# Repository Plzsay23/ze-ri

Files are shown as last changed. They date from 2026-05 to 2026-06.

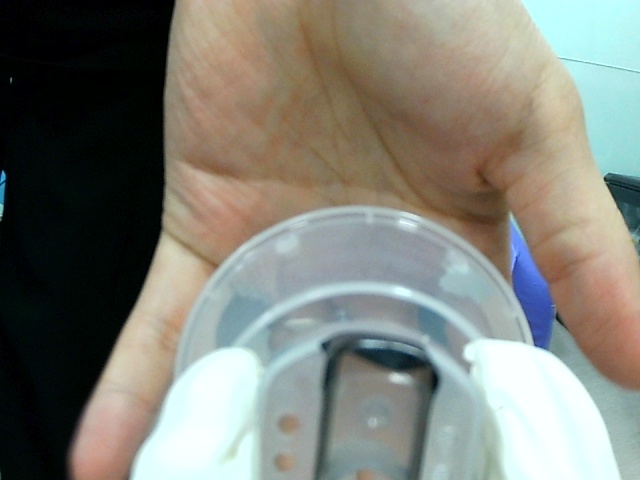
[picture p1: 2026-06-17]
debug/yolo_handoff/20260604_195928_raw.jpg

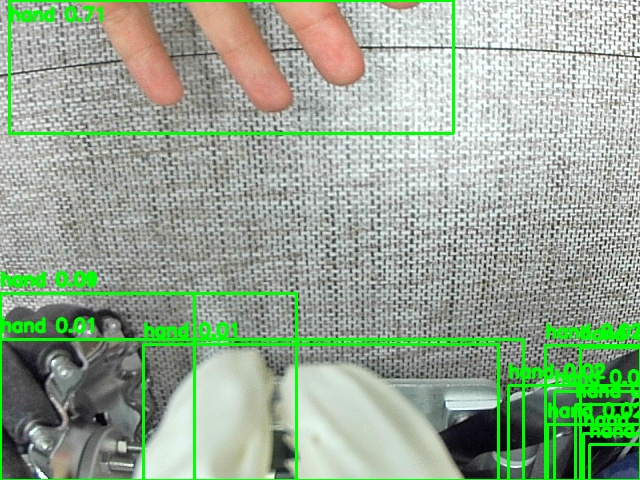
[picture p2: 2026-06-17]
debug/yolo_handoff/20260604_193629_yolo.jpg

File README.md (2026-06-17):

# Zero-Risk

Zero-Risk는 재난 상황 초동 조치를 위한 VLM 기반 지능형 모바일 매니퓰레이터입니다. RGB-D 카메라, 2D LiDAR, ReSpeaker Mic Array, SenseVoice STT, Edge-TTS, Qwen3-VL, SO-101 양팔 로봇팔, 4륜 메카넘 베이스를 ROS2 Jazzy 토픽으로 연결합니다.

## 주요 기능

- RGB-D 카메라와 LiDAR 기반 사람 접근 및 안전 정지
- ReSpeaker VAD/DOA와 SenseVoice 기반 음성 입력
- Edge-TTS 기반 구조 안내 발화
- Qwen3-VL 기반 구조 대상자 요청 판단
- 물, 산소마스크, 무전기 전달 VLA task routing
- SO-101 양팔 로봇팔 기반 물품 집기와 전달
- RGB, Depth, PointCloud, STT, TTS, VLM, VLA, 자율주행 상태 대시보드

## 환경

- Ubuntu 24.04
- ROS2 Jazzy
- Python 3.12
- NVIDIA Jetson Thor
- Intel RealSense D435i/D435if
- EAI X2 2D LiDAR
- ReSpeaker USB Mic Array v3.0
- SO-101 robot arm 2대

## 빌드

```bash
cd ~/ze-ri
source /opt/ros/jazzy/setup.bash
colcon build --base-paths ros2_ws/src --symlink-install
source ~/ze-ri/source_zeri.sh
```

## 수동 실행

각 명령은 별도 터미널에서 실행합니다.

```bash
cd ~/ze-ri
source ~/ze-ri/source_zeri.sh
```

카메라:

```bash
bash ~/ze-ri/scripts/camera_rgbd.sh
```

SLAM, LiDAR safety, base odometry:

```bash
bash ~/ze-ri/scripts/slam_depth_drive.sh
```

음성 방향 주행은 SLAM/base stack을 먼저 켠 뒤 실행합니다:

```bash
bash ~/ze-ri/scripts/voice_direction_drive.sh
```

STT, TTS, VLM:

```bash
bash ~/ze-ri/scripts/start_hri.sh
```

양팔 VLA:

```bash
bash ~/ze-ri/scripts/start_vla.sh
```

대시보드:

```bash
python3 ~/ze-ri/dashboard/dashboard_server.py
```

## 주요 토픽

- `/zeri/vlm/input_rgb`
- `/zeri/vlm/input_depth`
- `/stt/text`
- `/zeri/vlm/robot_speech`
- `/zeri/vlm/decision`
- `/zeri/vla/task_request`
- `/zeri/vla/status`
- `/cmd_vel_raw`
- `/cmd_vel`
- `/odom`
- `/scan_front`
- `/map`

## 스모크 테스트

```bash
python3 -m py_compile \
  ros2_ws/src/nb_voice_stt/nb_voice_stt/*.py \
  ros2_ws/src/zeri_base/zeri_base/*.py \
  ros2_ws/src/zeri_bringup/zeri_bringup/*.py \
  ros2_ws/src/zeri_camera/zeri_camera/*.py \
  ros2_ws/src/zeri_lidar/zeri_lidar/*.py \
  ros2_ws/src/zeri_voice/zeri_voice/*.py \
  src/lerobot/vlm_agent/*.py

python3 - <<'PY'
from pathlib import Path
import xml.etree.ElementTree as ET
for path in Path("ros2_ws/src").glob("*/package.xml"):
    ET.parse(path)
print("package.xml ok")
PY

bash -n source_zeri.sh source_zeri_vlm.sh scripts/*.sh
```

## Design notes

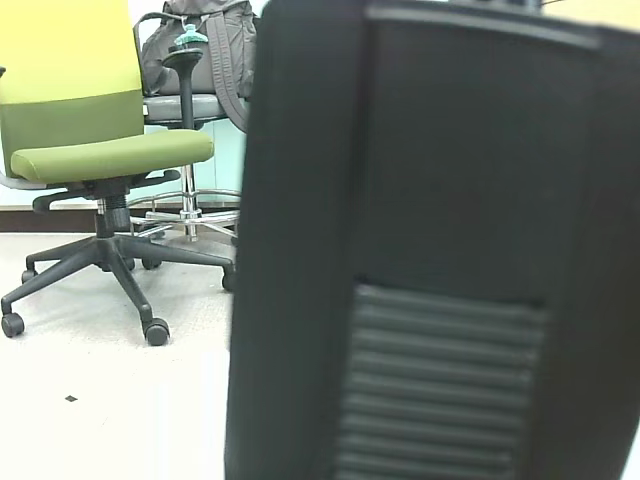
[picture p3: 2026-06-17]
config/vla/references/pick_wt/final_ep_0008.png

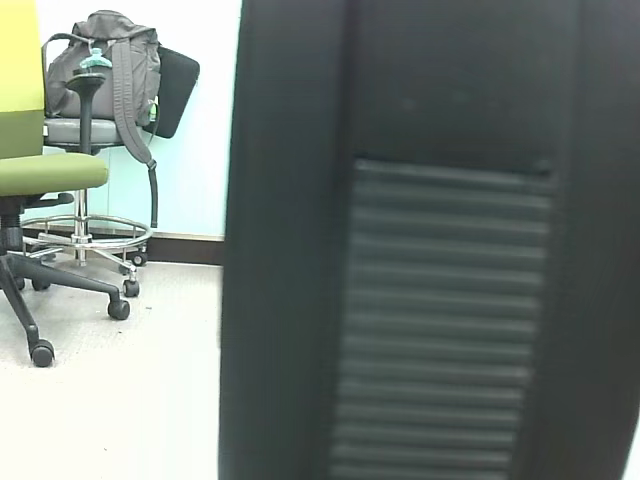
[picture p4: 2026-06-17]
config/vla/references/pick_wt/final_ep_0003.png

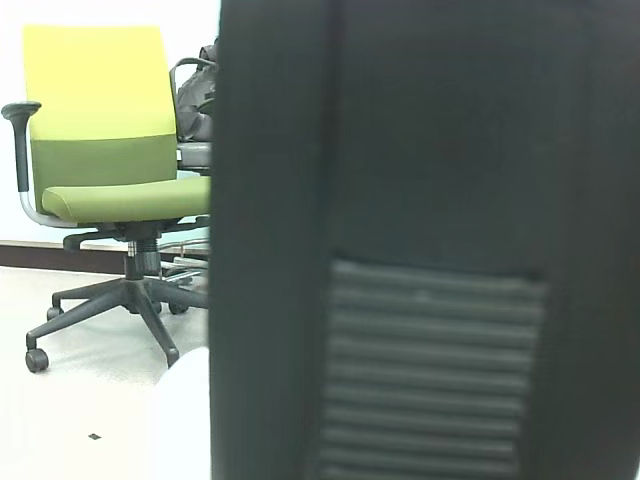
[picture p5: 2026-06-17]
config/vla/references/pick_wt/final_ep_0020.png

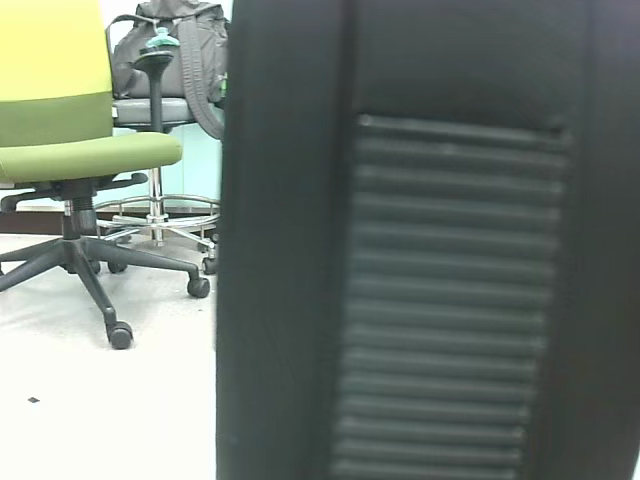
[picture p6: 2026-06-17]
config/vla/references/pick_wt/final_ep_0023.png

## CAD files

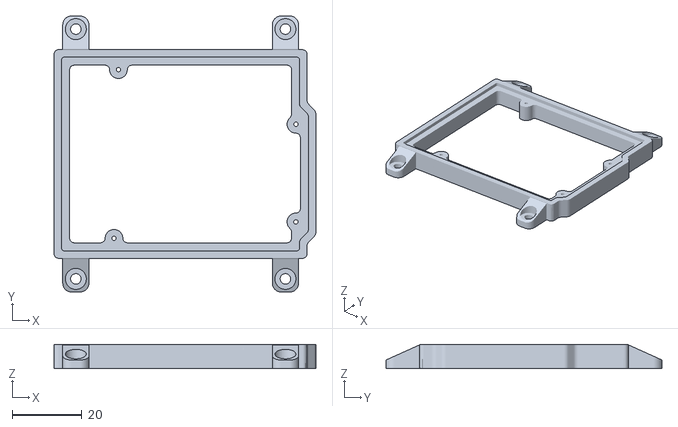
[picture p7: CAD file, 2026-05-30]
stl/mount/Mount_arduino.stl
74.9 x 79.0 x 7.00

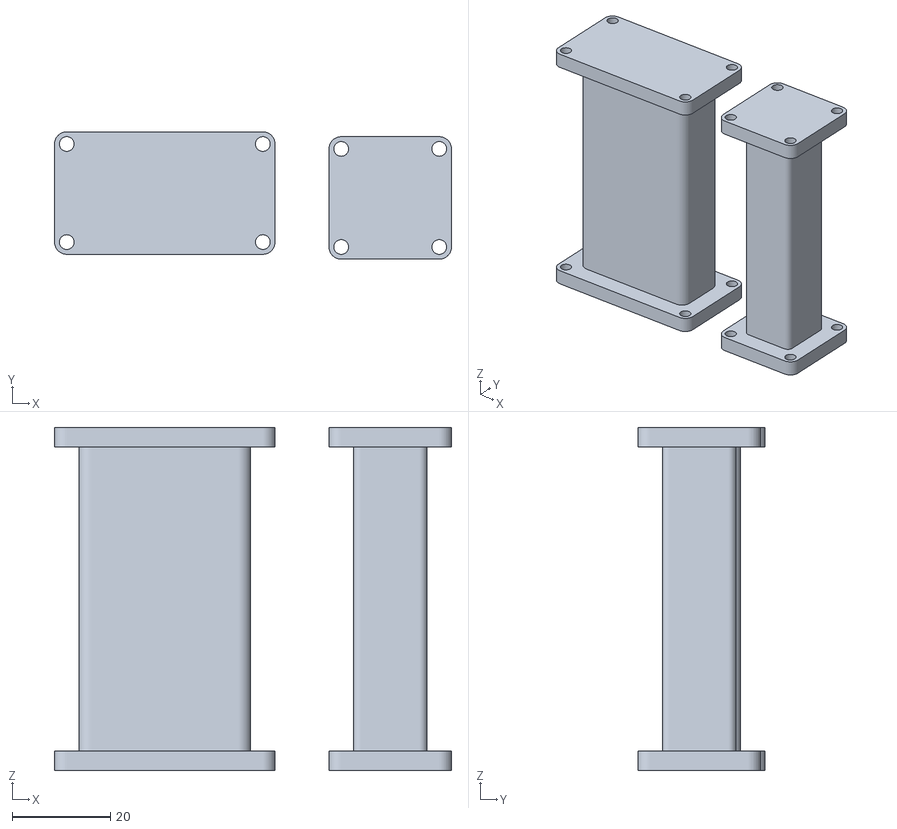
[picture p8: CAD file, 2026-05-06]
stl/others/Pillar.stl
81.0 x 26.0 x 70.0

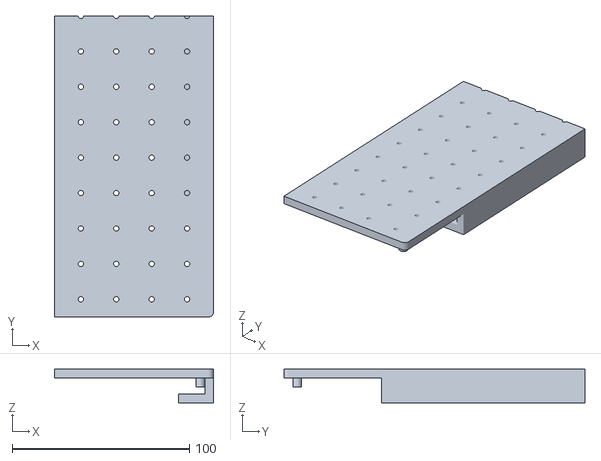
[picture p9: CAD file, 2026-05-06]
stl/plate/Plate_base_back_right.stl
90.0 x 170.0 x 19.0

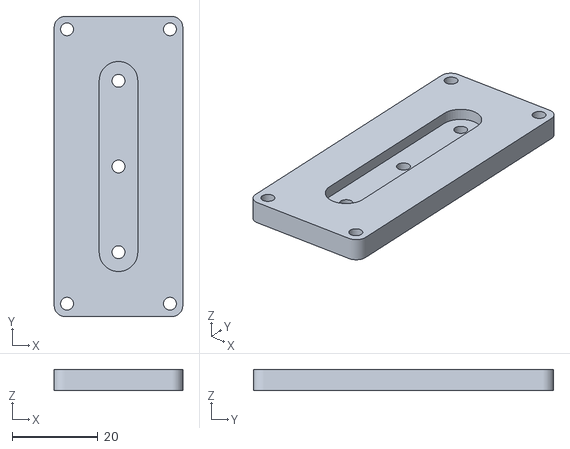
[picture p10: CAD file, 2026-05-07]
stl/mount/Mount_speaker.stl
30.0 x 70.0 x 5.00

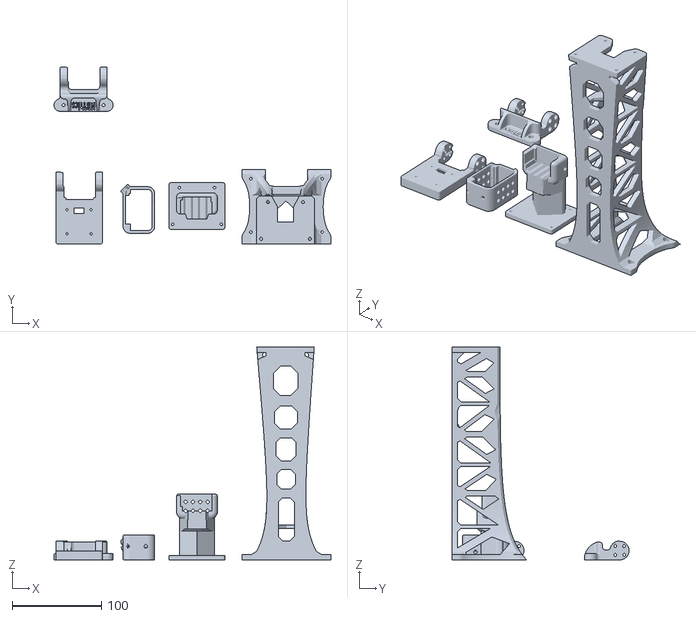
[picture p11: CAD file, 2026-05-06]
stl/others/Tower_camera.stl
311.0 x 198.9 x 239.0

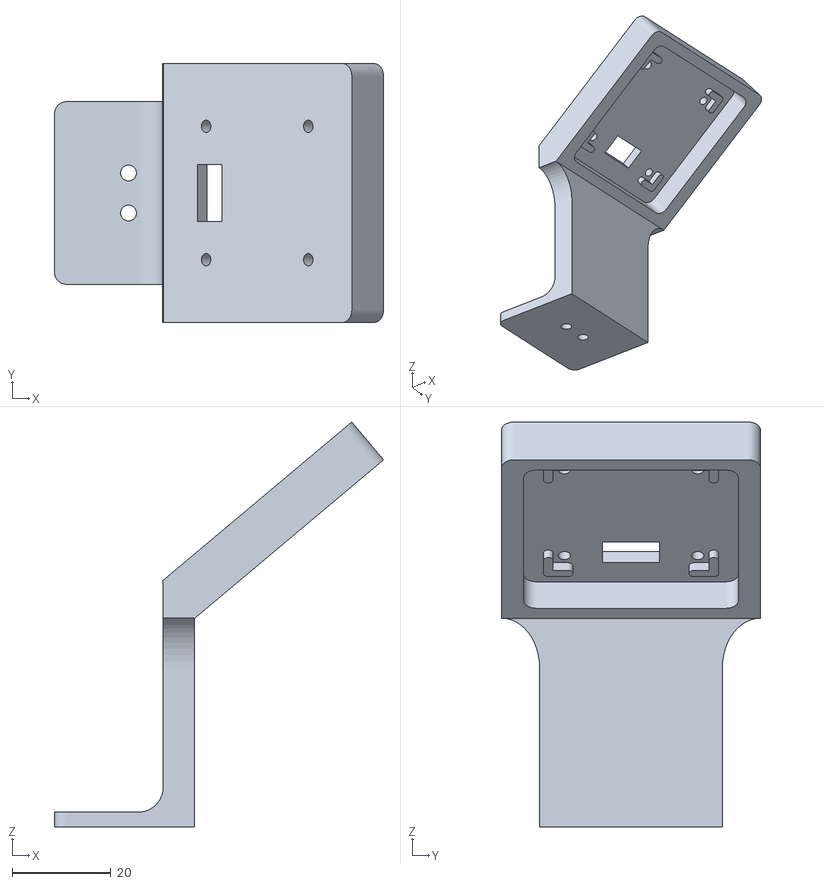
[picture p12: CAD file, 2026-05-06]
stl/mount/Mount_wrist_camera.stl
66.6 x 52.4 x 82.0

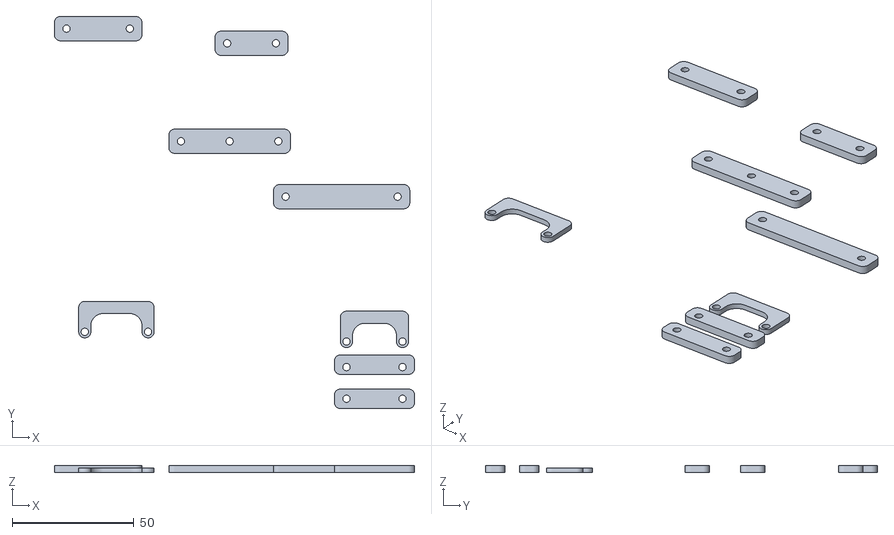
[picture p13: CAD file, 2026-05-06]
stl/others/Connectors.stl
148.0 x 161.0 x 3.00

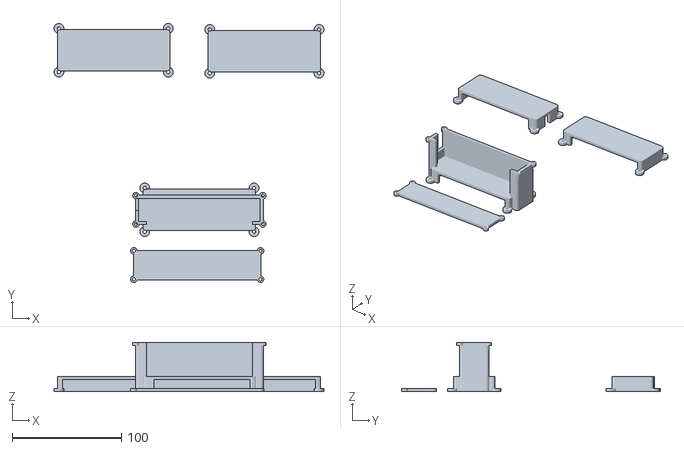
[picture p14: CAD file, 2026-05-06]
stl/mount/Mount_USB_hub.stl
247.0 x 237.0 x 45.0

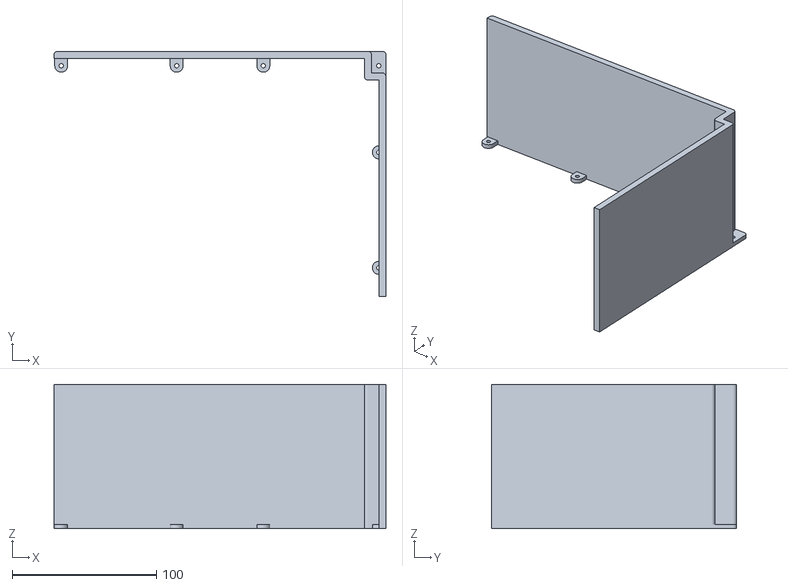
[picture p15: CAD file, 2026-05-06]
stl/others/Fence_left.stl
230.0 x 170.0 x 100.0

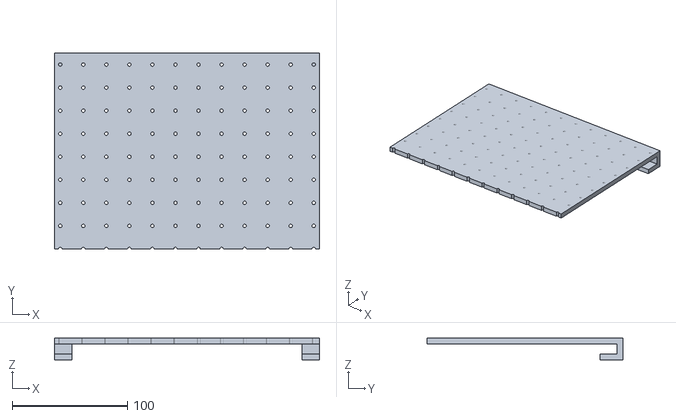
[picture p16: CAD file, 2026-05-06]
stl/plate/Plate_base_middle.stl
230.0 x 170.0 x 19.0

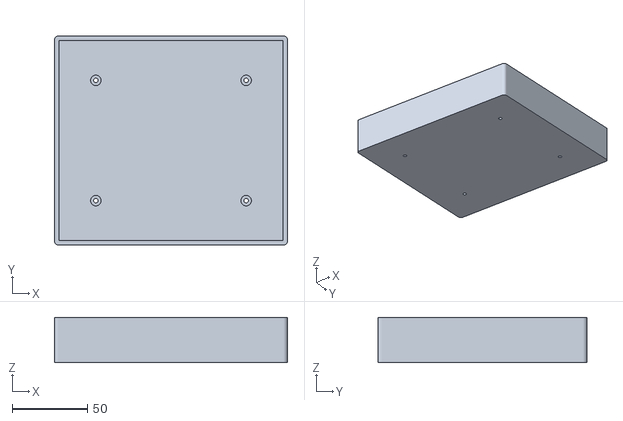
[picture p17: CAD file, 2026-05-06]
stl/mount/Mount_battery_16v.stl
155.0 x 139.0 x 30.0

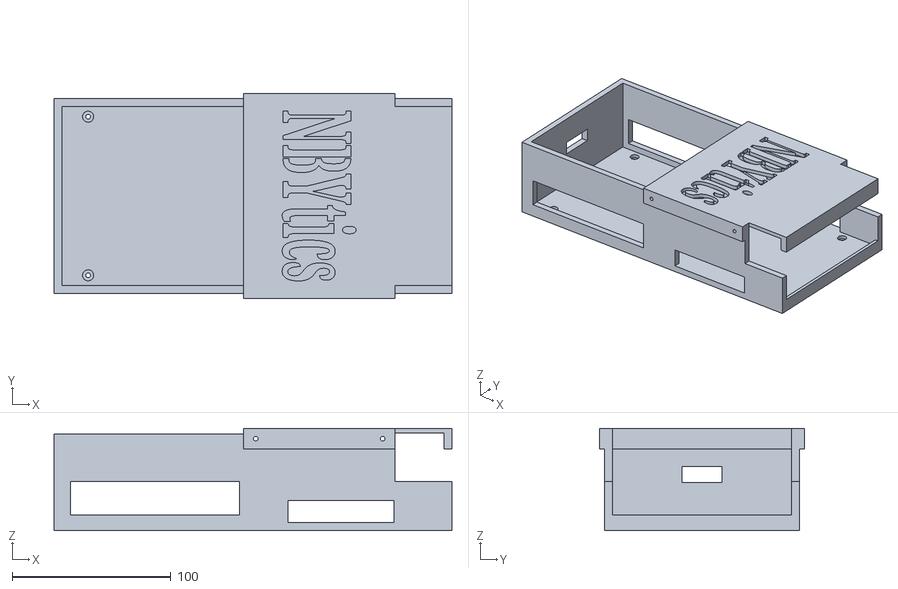
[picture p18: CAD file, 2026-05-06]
stl/mount/Mount_jetson_thor.stl
251.0 x 129.0 x 64.5

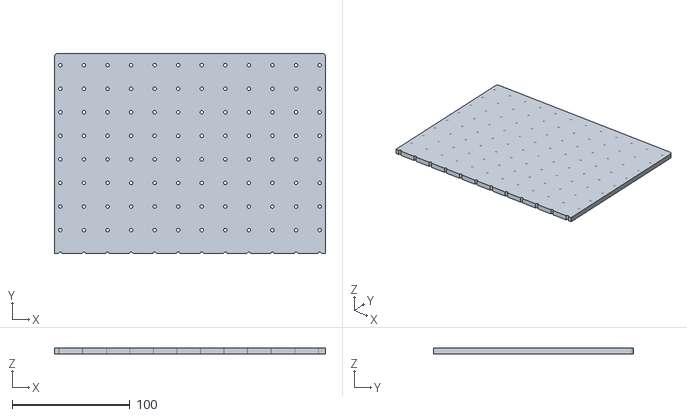
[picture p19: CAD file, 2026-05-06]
stl/plate/Plate_top.stl
230.0 x 170.0 x 5.00

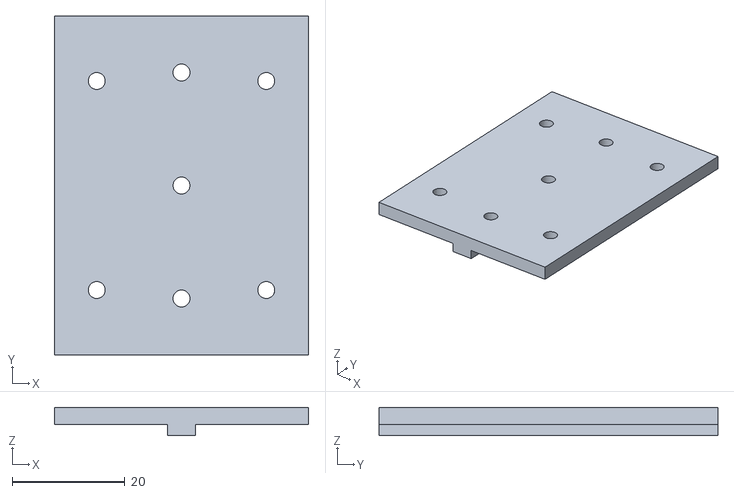
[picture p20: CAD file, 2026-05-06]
stl/mount/Mount_driver.stl
45.0 x 60.0 x 5.00

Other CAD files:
stl/plate/Plate_base_front_right.stl
stl/plate/Plate_base_back_left.stl
stl/others/Fence_right.stl
stl/plate/Plate_base_front_left.stl
stl/mount/Mount_battery_12v.stl
stl/mount/Mount_microphone.stl

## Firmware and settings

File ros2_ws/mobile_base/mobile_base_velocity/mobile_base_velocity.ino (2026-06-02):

#include <Encoder.h>
#include <math.h>
#include <string.h>

// ============================================================
// Ze-Ri Mobile Base Arduino Firmware
//
// Protocol:
//   V vx vy wz\n     vx, vy, wz in [-1.0, 1.0]
//   P pwm\n          set max PWM
//   X\n              smooth stop
//   Z\n              immediate stop
//
// IMPORTANT:
//   Acceleration command is NOT accepted.
//   There is NO "A accel decel" serial command.
//   Ramp values are fixed inside this firmware.
//
// Legacy lowercase keys for manual test:
//   w/s : forward/backward
//   a/d : turn left/right
//   q/e : strafe left/right
//   r/t/f/g : diagonal
//   x : smooth stop
//   z : immediate stop
//   l/m : PWM +10 / -10
//
// Encoder output:
//   ENC LF RF LR RR
// ============================================================


// ============================================================
// Motor pins
// ============================================================

#define PWMA 4
#define DIRA1 A5
#define DIRA2 A4

#define PWMB 6
#define DIRB1 43
#define DIRB2 42

#define PWMC 11
#define DIRC1 35
#define DIRC2 34

#define PWMD 7
#define DIRD1 37
#define DIRD2 36


// ============================================================
// Encoder pins
//
// Actual motor mapping:
//   A = RF
//   B = LF, inverted
//   C = RR
//   D = LR, inverted
// ============================================================

Encoder encA(18, 31);   // RF
Encoder encB(19, 38);   // LF, inverted
Encoder encC(3, 49);    // RR
Encoder encD(2, A1);    // LR, inverted


// ============================================================
// Speed / timing
// ============================================================

int Motor_PWM = 60;

const int MIN_MOTION_PWM = 18;

const unsigned long ENC_PERIOD_MS = 100;
const unsigned long CMD_TIMEOUT_MS = 800;
const unsigned long RAMP_PERIOD_MS = 20;

unsigned long lastEncMs = 0;
unsigned long lastCmdMs = 0;
unsigned long lastRampMs = 0;


// ============================================================
// Fixed internal ramp
//
// These values are NOT configurable through serial.
// Arduino must NOT receive acceleration/deceleration values.
// ============================================================

const float RAMP_UP_STEP = 0.025f;
const float RAMP_DOWN_STEP = 0.040f;


// ============================================================
// Wheel command state
//
// Wheel order:
//   LF RF LR RR
// ============================================================

float targetLF = 0.0f;
float targetRF = 0.0f;
float targetLR = 0.0f;
float targetRR = 0.0f;

float currentLF = 0.0f;
float currentRF = 0.0f;
float currentLR = 0.0f;
float currentRR = 0.0f;


// ============================================================
// Serial line buffer
// ============================================================

char lineBuf[96];
uint8_t lineLen = 0;
bool lineMode = false;


// ============================================================
// Motor low-level macros
// ============================================================

#define MOTORA_FORWARD(pwm)    do { digitalWrite(DIRA1, HIGH); digitalWrite(DIRA2, LOW);  analogWrite(PWMA, pwm); } while (0)
#define MOTORA_BACKOFF(pwm)    do { digitalWrite(DIRA1, LOW);  digitalWrite(DIRA2, HIGH); analogWrite(PWMA, pwm); } while (0)
#define MOTORA_STOP()          do { digitalWrite(DIRA1, LOW);  digitalWrite(DIRA2, LOW);  analogWrite(PWMA, 0);   } while (0)

#define MOTORB_FORWARD(pwm)    do { digitalWrite(DIRB1, LOW);  digitalWrite(DIRB2, HIGH); analogWrite(PWMB, pwm); } while (0)
#define MOTORB_BACKOFF(pwm)    do { digitalWrite(DIRB1, HIGH); digitalWrite(DIRB2, LOW);  analogWrite(PWMB, pwm); } while (0)
#define MOTORB_STOP()          do { digitalWrite(DIRB1, LOW);  digitalWrite(DIRB2, LOW);  analogWrite(PWMB, 0);   } while (0)

#define MOTORC_FORWARD(pwm)    do { digitalWrite(DIRC1, HIGH); digitalWrite(DIRC2, LOW);  analogWrite(PWMC, pwm); } while (0)
#define MOTORC_BACKOFF(pwm)    do { digitalWrite(DIRC1, LOW);  digitalWrite(DIRC2, HIGH); analogWrite(PWMC, pwm); } while (0)
#define MOTORC_STOP()          do { digitalWrite(DIRC1, LOW);  digitalWrite(DIRC2, LOW);  analogWrite(PWMC, 0);   } while (0)

#define MOTORD_FORWARD(pwm)    do { digitalWrite(DIRD1, LOW);  digitalWrite(DIRD2, HIGH); analogWrite(PWMD, pwm); } while (0)
#define MOTORD_BACKOFF(pwm)    do { digitalWrite(DIRD1, HIGH); digitalWrite(DIRD2, LOW);  analogWrite(PWMD, pwm); } while (0)
#define MOTORD_STOP()          do { digitalWrite(DIRD1, LOW);  digitalWrite(DIRD2, LOW);  analogWrite(PWMD, 0);   } while (0)


// ============================================================
// Utility
// ============================================================

float clampf(float x, float lo, float hi) {
  if (x < lo) return lo;
  if (x > hi) return hi;
  return x;
}

bool oppositeSign(float a, float b, float eps) {
  return fabs(a) > eps && fabs(b) > eps && (a * b) < 0.0f;
}

int scaledPwm(float v) {
  float a = fabs(v);

  if (a < 0.001f) {
    return 0;
  }

  int pwm = (int)(a * Motor_PWM + 0.5f);

  if (pwm > 0 && pwm < MIN_MOTION_PWM) {
    pwm = MIN_MOTION_PWM;
  }

  if (pwm > 255) {
    pwm = 255;
  }

  return pwm;
}


// ============================================================
// Motor signed output
// ============================================================

void motorA_signed(float v) {
  int pwm = scaledPwm(v);

  if (pwm == 0) {
    MOTORA_STOP();
  } else if (v > 0.0f) {
    MOTORA_FORWARD(pwm);
  } else {
    MOTORA_BACKOFF(pwm);
  }
}

void motorB_signed(float v) {
  int pwm = scaledPwm(v);

  if (pwm == 0) {
    MOTORB_STOP();
  } else if (v > 0.0f) {
    MOTORB_FORWARD(pwm);
  } else {
    MOTORB_BACKOFF(pwm);
  }
}

void motorC_signed(float v) {
  int pwm = scaledPwm(v);

  if (pwm == 0) {
    MOTORC_STOP();
  } else if (v > 0.0f) {
    MOTORC_FORWARD(pwm);
  } else {
    MOTORC_BACKOFF(pwm);
  }
}

void motorD_signed(float v) {
  int pwm = scaledPwm(v);

  if (pwm == 0) {
    MOTORD_STOP();
  } else if (v > 0.0f) {
    MOTORD_FORWARD(pwm);
  } else {
    MOTORD_BACKOFF(pwm);
  }
}


// ============================================================
// Wheel ramp
// ============================================================

float slewWheel(float current, float target) {
  target = clampf(target, -1.0f, 1.0f);

  // Avoid direct reverse. Pass through zero first.
  if (oppositeSign(current, target, 0.02f)) {
    target = 0.0f;
  }

  float diff = target - current;

  if (fabs(diff) < 0.0005f) {
    return target;
  }

  float step;

  if (fabs(target) < fabs(current)) {
    step = RAMP_DOWN_STEP;
  } else {
    step = RAMP_UP_STEP;
  }

  if (fabs(diff) <= step) {
    return target;
  }

  if (diff > 0.0f) {
    return current + step;
  }

  return current - step;
}

void setWheelTargets(float lf, float rf, float lr, float rr) {
  targetLF = clampf(lf, -1.0f, 1.0f);
  targetRF = clampf(rf, -1.0f, 1.0f);
  targetLR = clampf(lr, -1.0f, 1.0f);
  targetRR = clampf(rr, -1.0f, 1.0f);
}

void applyCurrentWheels() {
  // Actual motor mapping:
  //   A = RF
  //   B = LF
  //   C = RR
  //   D = LR
  motorB_signed(currentLF);
  motorA_signed(currentRF);
  motorD_signed(currentLR);
  motorC_signed(currentRR);
}

void updateMotorRamp() {
  unsigned long now = millis();

  if (now - lastRampMs < RAMP_PERIOD_MS) {
    return;
  }

  lastRampMs = now;

  currentLF = slewWheel(currentLF, targetLF);
  currentRF = slewWheel(currentRF, targetRF);
  currentLR = slewWheel(currentLR, targetLR);
  currentRR = slewWheel(currentRR, targetRR);

  applyCurrentWheels();
}

void immediateStopMotors() {
  targetLF = 0.0f;
  targetRF = 0.0f;
  targetLR = 0.0f;
  targetRR = 0.0f;

  currentLF = 0.0f;
  currentRF = 0.0f;
  currentLR = 0.0f;
  currentRR = 0.0f;

  MOTORA_STOP();
  MOTORB_STOP();
  MOTORC_STOP();
  MOTORD_STOP();
}

void smoothStopMotors() {
  setWheelTargets(0.0f, 0.0f, 0.0f, 0.0f);
}


// ============================================================
// Mecanum velocity command
//
// vx: forward +
// vy: left +
// wz: CCW / left turn +
// ============================================================

void driveVelocity(float vx, float vy, float wz) {
  vx = clampf(vx, -1.0f, 1.0f);
  vy = clampf(vy, -1.0f, 1.0f);
  wz = clampf(wz, -1.0f, 1.0f);

  // Wheel order:
  //   LF RF LR RR
  float lf = vx + vy + wz;
  float rf = vx - vy - wz;
  float lr = vx - vy + wz;
  float rr = vx + vy - wz;

  float maxAbs = fabs(lf);

  if (fabs(rf) > maxAbs) maxAbs = fabs(rf);
  if (fabs(lr) > maxAbs) maxAbs = fabs(lr);
  if (fabs(rr) > maxAbs) maxAbs = fabs(rr);

  if (maxAbs > 1.0f) {
    lf /= maxAbs;
    rf /= maxAbs;
    lr /= maxAbs;
    rr /= maxAbs;
  }

  setWheelTargets(lf, rf, lr, rr);
  lastCmdMs = millis();
}


// ============================================================
// Legacy lowercase key command
//
// Uppercase A is intentionally NOT used as turn command.
// This prevents accidental old "A accel decel" input from moving robot.
// ============================================================

bool isLegacyKey(char cmd) {
  return (
    cmd == 'w' ||
    cmd == 's' ||
    cmd == 'a' ||
    cmd == 'd' ||
    cmd == 'q' ||
    cmd == 'e' ||
    cmd == 'r' ||
    cmd == 't' ||
    cmd == 'f' ||
    cmd == 'g' ||
    cmd == 'x' ||
    cmd == 'z' ||
    cmd == 'l' ||
    cmd == 'm'
  );
}

void handleKeyCommand(char cmd) {
  if (cmd == '\n' || cmd == '\r' || cmd == ' ' || cmd == '\t') {
    return;
  }

  switch (cmd) {
    case 'w':
      driveVelocity(1.0f, 0.0f, 0.0f);
      break;

    case 's':
      driveVelocity(-1.0f, 0.0f, 0.0f);
      break;

    case 'a':
      driveVelocity(0.0f, 0.0f, 1.0f);
      break;

    case 'd':
      driveVelocity(0.0f, 0.0f, -1.0f);
      break;

    case 'q':
      driveVelocity(0.0f, 1.0f, 0.0f);
      break;

    case 'e':
      driveVelocity(0.0f, -1.0f, 0.0f);
      break;

    case 'r':
      driveVelocity(0.7f, 0.7f, 0.0f);
      break;

    case 't':
      driveVelocity(0.7f, -0.7f, 0.0f);
      break;

    case 'f':
      driveVelocity(-0.7f, 0.7f, 0.0f);
      break;

    case 'g':
      driveVelocity(-0.7f, -0.7f, 0.0f);
      break;

    case 'x':
      smoothStopMotors();
      lastCmdMs = millis();
      break;

    case 'z':
      immediateStopMotors();
      lastCmdMs = millis();
      break;

    case 'l':
      Motor_PWM += 10;
      if (Motor_PWM > 255) Motor_PWM = 255;
      Serial.print("PWM ");
      Serial.println(Motor_PWM);
      break;

    case 'm':
      Motor_PWM -= 10;
      if (Motor_PWM < 0) Motor_PWM = 0;
      Serial.print("PWM ");
      Serial.println(Motor_PWM);
      break;

    default:
      break;
  }
}


// ============================================================
// Encoder publish
//
// Output order must match base node:
//   ENC LF RF LR RR
// ============================================================

void publishEncoder() {
  long rawA = encA.read();     // RF
  long rawB = -encB.read();    // LF inverted
  long rawC = encC.read();     // RR
  long rawD = -encD.read();    // LR inverted

  long lf = rawB;
  long rf = rawA;
  long lr = rawD;
  long rr = rawC;

  Serial.print("ENC ");
  Serial.print(lf);
  Serial.print(" ");
  Serial.print(rf);
  Serial.print(" ");
  Serial.print(lr);
  Serial.print(" ");
  Serial.println(rr);
}


// ============================================================
// Line protocol
// ============================================================

void handleLine(char *line) {
  char *cmd = strtok(line, " ,\t");

  if (cmd == NULL) {
    return;
  }

  // V vx vy wz
  if (cmd[0] == 'V' || cmd[0] == 'v') {
    char *sx = strtok(NULL, " ,\t");
    char *sy = strtok(NULL, " ,\t");
    char *sw = strtok(NULL, " ,\t");

    if (sx == NULL || sy == NULL || sw == NULL) {
      smoothStopMotors();
      return;
    }

    float vx = atof(sx);
    float vy = atof(sy);
    float wz = atof(sw);

    driveVelocity(vx, vy, wz);
    return;
  }

  // P pwm
  if (cmd[0] == 'P' || cmd[0] == 'p') {
    char *spwm = strtok(NULL, " ,\t");

    if (spwm != NULL) {
      Motor_PWM = atoi(spwm);

      if (Motor_PWM < 0) Motor_PWM = 0;
      if (Motor_PWM > 255) Motor_PWM = 255;

      Serial.print("PWM ");
      Serial.println(Motor_PWM);
    }

    return;
  }

  // X smooth stop
  if (cmd[0] == 'X' || cmd[0] == 'x') {
    smoothStopMotors();
    lastCmdMs = millis();
    return;
  }

  // Z immediate stop
  if (cmd[0] == 'Z' || cmd[0] == 'z') {
    immediateStopMotors();
    lastCmdMs = millis();
    return;
  }

  // No acceleration command is accepted.
  // Old "A accel decel" lines are intentionally ignored.
  if (cmd[0] == 'A') {
    return;
  }

  // Single lowercase key fallback
  if (cmd[1] == '\0' && isLegacyKey(cmd[0])) {
    handleKeyCommand(cmd[0]);
    return;
  }
}

void readSerialCommands() {
  while (Serial.available()) {
    char c = Serial.read();

    if (lineMode) {
      if (c == '\n' || c == '\r') {
        lineBuf[lineLen] = '\0';
        handleLine(lineBuf);
        lineLen = 0;
        lineMode = false;
      } else if (lineLen < sizeof(lineBuf) - 1) {
        lineBuf[lineLen++] = c;
      } else {
        lineLen = 0;
        lineMode = false;
        immediateStopMotors();
      }

      continue;
    }

    // Line-based commands.
    //
    // V/P are valid line commands.
    // A is consumed as a line only to safely ignore old acceleration input.
    // It does NOT configure acceleration.
    if (c == 'V' || c == 'v' ||
        c == 'P' || c == 'p' ||
        c == 'A') {
      lineMode = true;
      lineLen = 0;
      lineBuf[lineLen++] = c;
      continue;
    }

    // Direct immediate commands
    if (c == 'X') {
      smoothStopMotors();
      lastCmdMs = millis();
      continue;
    }

    if (c == 'Z') {
      immediateStopMotors();
      lastCmdMs = millis();
      continue;
    }

    // Single lowercase key commands
    if (isLegacyKey(c)) {
      handleKeyCommand(c);
      continue;
    }

    // Ignore everything else
  }
}


// ============================================================
// Setup / loop
// ============================================================

void setup() {
  Serial.begin(115200);

  pinMode(PWMA, OUTPUT);
  pinMode(DIRA1, OUTPUT);
  pinMode(DIRA2, OUTPUT);

  pinMode(PWMB, OUTPUT);
  pinMode(DIRB1, OUTPUT);
  pinMode(DIRB2, OUTPUT);

  pinMode(PWMC, OUTPUT);
  pinMode(DIRC1, OUTPUT);
  pinMode(DIRC2, OUTPUT);

  pinMode(PWMD, OUTPUT);
  pinMode(DIRD1, OUTPUT);
  pinMode(DIRD2, OUTPUT);

  immediateStopMotors();

  lastCmdMs = millis();
  lastEncMs = millis();
  lastRampMs = millis();

  Serial.println("READY ZE_RI_BASE_VELOCITY_FIXED_RAMP");
  Serial.println("CMD: V vx vy wz  where vx,vy,wz in [-1,1]");
  Serial.println("CMD: P pwm");
  Serial.println("CMD: X smooth stop");
  Serial.println("CMD: Z immediate stop");
  Serial.println("NO CMD: A accel decel");
  Serial.println("KEYS lowercase only: w/s/a/d/q/e/r/t/f/g/x/z/l/m");
  Serial.println("FORMAT: ENC LF RF LR RR");
}

void loop() {
  unsigned long now = millis();

  readSerialCommands();
  updateMotorRamp();

  // If command stream stops, stop safely.
  if (now - lastCmdMs > CMD_TIMEOUT_MS) {
    immediateStopMotors();
    lastCmdMs = now;
  }

  if (now - lastEncMs >= ENC_PERIOD_MS) {
    lastEncMs = now;
    publishEncoder();
  }
}

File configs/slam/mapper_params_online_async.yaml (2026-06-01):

slam_toolbox:
  ros__parameters:
    use_sim_time: false

    # Frames
    odom_frame: odom
    map_frame: map
    base_frame: base_link

    # LiDAR topic
    scan_topic: /scan_front

    # Mapping mode
    mode: mapping
    debug_logging: false
    throttle_scans: 1
    transform_publish_period: 0.02
    map_update_interval: 1.0
    resolution: 0.05

    # LiDAR range
    max_laser_range: 6.0
    minimum_time_interval: 0.0

    # TF
    transform_timeout: 0.5
    tf_buffer_duration: 30.0

    # Scan matching
    use_scan_matching: true
    use_scan_barycenter: true
    minimum_travel_distance: 0.05
    minimum_travel_heading: 0.05
    scan_buffer_size: 10
    scan_buffer_maximum_scan_distance: 10.0

    # Loop closure
    do_loop_closing: true
    loop_search_maximum_distance: 3.0
    loop_match_minimum_chain_size: 10
    loop_match_maximum_variance_coarse: 3.0
    loop_match_minimum_response_coarse: 0.35
    loop_match_minimum_response_fine: 0.45

    # Correlation search
    correlation_search_space_dimension: 0.5
    correlation_search_space_resolution: 0.01
    correlation_search_space_smear_deviation: 0.1

    # Loop closure correlation search
    loop_search_space_dimension: 8.0
    loop_search_space_resolution: 0.05
    loop_search_space_smear_deviation: 0.03

    # Scan matcher penalties
    distance_variance_penalty: 0.5
    angle_variance_penalty: 1.0
    fine_search_angle_offset: 0.00349
    coarse_search_angle_offset: 0.349
    coarse_angle_resolution: 0.0349
    minimum_angle_penalty: 0.9
    minimum_distance_penalty: 0.5
    use_response_expansion: true

    # Solver
    solver_plugin: solver_plugins::CeresSolver
    ceres_linear_solver: SPARSE_NORMAL_CHOLESKY
    ceres_preconditioner: SCHUR_JACOBI
    ceres_trust_strategy: LEVENBERG_MARQUARDT
    ceres_dogleg_type: TRADITIONAL_DOGLEG
    ceres_loss_function: None

    # Safety
    stack_size_to_use: 40000000
    enable_interactive_mode: true

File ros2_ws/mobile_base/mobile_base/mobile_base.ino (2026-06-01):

#include <Encoder.h>

// ===== 모터 핀 정의: 네가 확인한 정상 동작 핀 기준 =====
#define PWMA 4
#define DIRA1 A5
#define DIRA2 A4

#define PWMB 6
#define DIRB1 43
#define DIRB2 42

#define PWMC 11
#define DIRC1 35
#define DIRC2 34

#define PWMD 7
#define DIRD1 37
#define DIRD2 36

// ===== Encoder 핀 =====
// 실제 확인된 encoder 커넥터 기준
Encoder encA(18, 31);   // 실제 RF
Encoder encB(19, 38);   // 실제 LF, 부호 반대
Encoder encC(3, 49);    // 실제 RR
Encoder encD(2, A1);    // 실제 LR, 부호 반대

// ===== 속도 설정 =====
int Motor_PWM = 30;

// encoder 출력 주기
const unsigned long ENC_PERIOD_MS = 100;
unsigned long lastEncMs = 0;

// 명령 timeout: 키 입력 끊기면 자동 정지
const unsigned long CMD_TIMEOUT_MS = 800;
unsigned long lastCmdMs = 0;

// ===== 모터 제어 매크로: 네 기존 코드 그대로 =====
#define MOTORA_FORWARD(pwm)    do{digitalWrite(DIRA1,HIGH); digitalWrite(DIRA2,LOW);  analogWrite(PWMA,pwm);}while(0)
#define MOTORA_BACKOFF(pwm)    do{digitalWrite(DIRA1,LOW);  digitalWrite(DIRA2,HIGH); analogWrite(PWMA,pwm);}while(0)
#define MOTORA_STOP()          do{digitalWrite(DIRA1,LOW);  digitalWrite(DIRA2,LOW);  analogWrite(PWMA,0);}while(0)

#define MOTORB_FORWARD(pwm)    do{digitalWrite(DIRB1,LOW);  digitalWrite(DIRB2,HIGH); analogWrite(PWMB,pwm);}while(0)
#define MOTORB_BACKOFF(pwm)    do{digitalWrite(DIRB1,HIGH); digitalWrite(DIRB2,LOW);  analogWrite(PWMB,pwm);}while(0)
#define MOTORB_STOP()          do{digitalWrite(DIRB1,LOW);  digitalWrite(DIRB2,LOW);  analogWrite(PWMB,0);}while(0)

#define MOTORC_FORWARD(pwm)    do{digitalWrite(DIRC1,HIGH); digitalWrite(DIRC2,LOW);  analogWrite(PWMC,pwm);}while(0)
#define MOTORC_BACKOFF(pwm)    do{digitalWrite(DIRC1,LOW);  digitalWrite(DIRC2,HIGH); analogWrite(PWMC,pwm);}while(0)
#define MOTORC_STOP()          do{digitalWrite(DIRC1,LOW);  digitalWrite(DIRC2,LOW);  analogWrite(PWMC,0);}while(0)

#define MOTORD_FORWARD(pwm)    do{digitalWrite(DIRD1,LOW);  digitalWrite(DIRD2,HIGH); analogWrite(PWMD,pwm);}while(0)
#define MOTORD_BACKOFF(pwm)    do{digitalWrite(DIRD1,HIGH); digitalWrite(DIRD2,LOW);  analogWrite(PWMD,pwm);}while(0)
#define MOTORD_STOP()          do{digitalWrite(DIRD1,LOW);  digitalWrite(DIRD2,LOW);  analogWrite(PWMD,0);}while(0)

// ===== 기본 이동 =====
void moveForward() {
  MOTORA_FORWARD(Motor_PWM);
  MOTORB_FORWARD(Motor_PWM);
  MOTORC_FORWARD(Motor_PWM);
  MOTORD_FORWARD(Motor_PWM);
}

void moveBackward() {
  MOTORA_BACKOFF(Motor_PWM);
  MOTORB_BACKOFF(Motor_PWM);
  MOTORC_BACKOFF(Motor_PWM);
  MOTORD_BACKOFF(Motor_PWM);
}

void stopMotors() {
  MOTORA_STOP();
  MOTORB_STOP();
  MOTORC_STOP();
  MOTORD_STOP();
}

// ===== 회전 =====
void turnLeft() {
  MOTORA_BACKOFF(Motor_PWM);
  MOTORB_FORWARD(Motor_PWM);
  MOTORC_BACKOFF(Motor_PWM);
  MOTORD_FORWARD(Motor_PWM);
}

void turnRight() {
  MOTORA_FORWARD(Motor_PWM);
  MOTORB_BACKOFF(Motor_PWM);
  MOTORC_FORWARD(Motor_PWM);
  MOTORD_BACKOFF(Motor_PWM);
}

// ===== 메카넘 평행이동 =====
void strafeLeft() {
  MOTORA_BACKOFF(Motor_PWM);
  MOTORB_FORWARD(Motor_PWM);
  MOTORC_FORWARD(Motor_PWM);
  MOTORD_BACKOFF(Motor_PWM);
}

void strafeRight() {
  MOTORA_FORWARD(Motor_PWM);
  MOTORB_BACKOFF(Motor_PWM);
  MOTORC_BACKOFF(Motor_PWM);
  MOTORD_FORWARD(Motor_PWM);
}

// ===== 대각선 =====
void diagFrontLeft() {
  MOTORA_STOP();
  MOTORB_FORWARD(Motor_PWM);
  MOTORC_FORWARD(Motor_PWM);
  MOTORD_STOP();
}

void diagFrontRight() {
  MOTORA_FORWARD(Motor_PWM);
  MOTORB_STOP();
  MOTORC_STOP();
  MOTORD_FORWARD(Motor_PWM);
}

void diagBackLeft() {
  MOTORA_BACKOFF(Motor_PWM);
  MOTORB_STOP();
  MOTORC_STOP();
  MOTORD_BACKOFF(Motor_PWM);
}

void diagBackRight() {
  MOTORA_STOP();
  MOTORB_BACKOFF(Motor_PWM);
  MOTORC_BACKOFF(Motor_PWM);
  MOTORD_STOP();
}

// ===== Encoder 출력 =====
// 최종 출력: ENC LF RF LR RR
void publishEncoder() {
  long rawA = encA.read();     // 실제 RF
  long rawB = -encB.read();    // 실제 LF
  long rawC = encC.read();     // 실제 RR
  long rawD = -encD.read();    // 실제 LR

  long lf = rawB;
  long rf = rawA;
  long lr = rawD;
  long rr = rawC;

  Serial.print("ENC ");
  Serial.print(lf);
  Serial.print(" ");
  Serial.print(rf);
  Serial.print(" ");
  Serial.print(lr);
  Serial.print(" ");
  Serial.println(rr);
}

// ===== 명령 처리 =====
void handleCommand(char cmd) {
  if (cmd == '\n' || cmd == '\r') return;

  switch (cmd) {
    case 'w': case 'W':
      moveForward();
      lastCmdMs = millis();
      break;

    case 's': case 'S':
      moveBackward();
      lastCmdMs = millis();
      break;

    case 'a': case 'A':
      turnLeft();
      lastCmdMs = millis();
      break;

    case 'd': case 'D':
      turnRight();
      lastCmdMs = millis();
      break;

    case 'q': case 'Q':
      strafeLeft();
      lastCmdMs = millis();
      break;

    case 'e': case 'E':
      strafeRight();
      lastCmdMs = millis();
      break;

    case 'r': case 'R':
      diagFrontLeft();
      lastCmdMs = millis();
      break;

    case 't': case 'T':
      diagFrontRight();
      lastCmdMs = millis();
      break;

    case 'f': case 'F':
      diagBackLeft();
      lastCmdMs = millis();
      break;

    case 'g': case 'G':
      diagBackRight();
      lastCmdMs = millis();
      break;

    case 'x': case 'X':
      stopMotors();
      break;

    case 'l': case 'L':
      Motor_PWM += 10;
      if (Motor_PWM > 255) Motor_PWM = 255;
      break;

    case 'm': case 'M':
      Motor_PWM -= 10;
      if (Motor_PWM < 0) Motor_PWM = 0;
      break;
  }
}

// ===== 초기 설정 =====
void setup() {
  Serial.begin(115200);

  pinMode(PWMA, OUTPUT);
  pinMode(DIRA1, OUTPUT);
  pinMode(DIRA2, OUTPUT);

  pinMode(PWMB, OUTPUT);
  pinMode(DIRB1, OUTPUT);
  pinMode(DIRB2, OUTPUT);

  pinMode(PWMC, OUTPUT);
  pinMode(DIRC1, OUTPUT);
  pinMode(DIRC2, OUTPUT);

  pinMode(PWMD, OUTPUT);
  pinMode(DIRD1, OUTPUT);
  pinMode(DIRD2, OUTPUT);

  stopMotors();

  lastCmdMs = millis();
  lastEncMs = millis();

  Serial.println("READY TELEOP_WITH_ENCODER");
  Serial.println("FORMAT: ENC LF RF LR RR");
}

// ===== 메인 루프 =====
void loop() {
  unsigned long now = millis();

  while (Serial.available()) {
    char cmd = Serial.read();
    handleCommand(cmd);
  }

  // 명령 끊기면 자동 정지
  if (now - lastCmdMs > CMD_TIMEOUT_MS) {
    stopMotors();
  }

  // encoder 출력
  if (now - lastEncMs >= ENC_PERIOD_MS) {
    lastEncMs = now;
    publishEncoder();
  }
}

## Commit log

2026-05-06 Add stls
    [Connectors.stl, Fence_left.stl, Fence_right.stl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]
2026-05-07 Add Mount_speaker
    [Mount_speaker.stl]
2026-05-12 Fixed fixed camera keys to dynamic camera keys
2026-05-13 Fixed record error v1
    [video_utils.py]
2026-05-14 Fixed camera topics
2026-05-14 Add realsense camera manager4
2026-05-14 Fixed dashboard camera vetical length
2026-05-20 Add NBYtics
    [odas.cfg]
2026-05-30 Add led ros
    [Mount_arduino.stl]
